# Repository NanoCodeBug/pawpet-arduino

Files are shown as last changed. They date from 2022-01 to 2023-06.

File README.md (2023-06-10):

# PawPet
Hi! This is the deprecated ardiuno-c++ based codebase, I've moved to a Rust codebase at https://github.com/NanoCodeBug/pawpet. 

# Build Instructions

Arduino SDK, pin layout of board is identical to a Adafruit Feather M0. 

## Linux Arduino SDK and Dependency Setup
tools/linux/sdk-setup.sh

tools/linux/build.sh

## Windows Arduino SDK and Dependency Setup
tools/win/sdk-setup.ps1

tools/win/build.ps1

## Mac Arduino SDK and Dependency Setup
tools/osx/sdk-setup.ps1

tools/osx/build.ps1

# Bootloader Instructions

1. flash adafruit bootloader https://github.com/adafruit/uf2-samdx1
2. set boot brotection fuses to 8kb (bootprot fuse value 0x2)
3. (optional) flash `pawos_setup.hex`
4. disable BOD33 fuse via `pawos_setup.hex` or preffered programmer device

# Flash Instructions

1. connect device via usb
2. double click reset button to enter bootloader
3. flash pawos via arduino-cli (`tools/<plat>/flash.sh`)

# Update Instructions
1. wake PawPet from sleep
2. connect via USB
3. flash pawos via arduino-cli (`tools/<plat>/flash.sh`)

TODO: update instructions that use UF2 instead, should be possible to use a script to put the device into bootloader mode, and then copy the file over via system file browser, or dynamically detect the device attach via usb id and drive name.

TODO: consider a self packaged C# exe or python script?

TODO: look into using openocd for flashing bootloader
TODO: fork adafruit bootloader to have low power operation enabled by default, bootloader blocks startup below 2.2v right now. in theory device can operate to 1.9v before display cuts out

---
# Simulator
A tool to simulate the pawpad on the computer.  
Currently only supports Windows.

## Requirements:

- [Visual Studio Community/MSVC](https://visualstudio.microsoft.com/vs/community/)
- [cmake](https://cmake.org/)
- [SDL2](https://github.com/libsdl-org/SDL/releases)
- [ninja](https://github.com/ninja-build/ninja/releases)
- [emsdk](https://emscripten.org/index.html) (Optional for webSimulator)

### Visual Studio Community
When setting up visual studio community, make sure to select these features:
"Desktop Development with C++"
as we require MSVC  
If you are using VSCode, see the following notes on launching VSCode from the Developer command prompt:  
(https://code.visualstudio.com/docs/cpp/config-msvc#_check-your-microsoft-visual-c-installation)

TODO: Could this possibly be switched to MinCG instead of using MSVC to remove the dependency of Visual Studio Community? [See here](https://code.visualstudio.com/docs/cpp/config-mingw)

### cmake
Install cmake to `C:\Program Files\CMake`

### SDL2
Download `SDL2-devel-[VERSION]-VC.zip` and place SDL2 in `.\simulator\SDL2`

### Ninja
Extract Ninja to `%userprofile%\dev\ninja.exe`

### emsdk
TODO

## Build the simulator
SDL2 and Webasm wrappers.

`tools/win/build.ps1 -simulator`

builds a SDL2 exe version of the pawpet, can be run from `.\build\win32\pawpet.exe`

`tools/win/build.ps1 -webSimulator`

builds a webasm version of the pawpet

## Controls
The Simulator uses the following controls:
```
 - Arrow Keys: dpad operation
 - Z - A Button: Open menu
 - X - B Button
 - C - C Button
 - V - P Button: Select
```

Additional Information in [simulator notes](simulator/notes.md)

---
# Licensing 

## Code
All code is licensed under the MIT license.

## Assets
Graphics, art, and models found in `sprites` and `paw-case` are licensed under the Creative Commons Attribution-NonCommercial 4.0 International Public License.

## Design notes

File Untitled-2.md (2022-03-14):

TODO:
validate clock toggle rate is 30hz and fix counters as needed 
need phillips screws for the back
need more heat set inserts
need more 470/480 ohm 805 resistors

https://forum.arduino.cc/t/samd21-power-consumption-too-high-in-active-mode/668966/2

Generic clock generator 0               8 division factor bits - DIV[7:0]
Generic clock generator 1               16 division factor bits - DIV[15:0]
Generic clock generators 2              5 division factor bits - DIV[4:0]
Generic clock generators 3 - 8          8 division factor bits - DIV[7:0]

rtc will be on anyways for time keeping

add BOD33 disable in bootloader flashing scripts?

condition where NVM RWS being 1 in bootloader will prevent startup below 2.1v
which is in theory near the end of useful battery life anyways

add ability for poweroff requiring push button reset?
from system menu and for when battery is low
- how to do this? disable all clocks?

display says it operates down 2.7v
- max frame frequency of 65hz?
- claims EXTCOMIN should be below framerate frequency, does not indicate why
- extcom freq of 54-65hz

3) A still image should be displayed less than two hours, if it is necessary to display still image longer than two 
hour, display image data must be refreshed in order to avoid sticking image on LCD panel

Memory LCDs do not generate this signal internally. It must be supplied using one of two methods: 
software, or external clock...
When the software clock is selected [EXTMODE = L], bit V of the command bit string sets the state of VCOM. 
See Figure 2. This bit must toggle (by writing to the panel) at least once per second. 

Power Scenario 1 
1hz write 1hz refresh
Here all of the pixels will be written to the panel once per second. For the 1.35-inch panel, the quiescent 
current for the panel is 2.1μA. Each write to the panel (assuming that the entire panel is written), takes 
360μA; and lasts for about 5.38ms (assuming a 2 MHz SPI clock speed). 
If averaged over a second, this amounts to an “average” currant draw of approximately 2μa. Therefore, the 
panel would have an average power draw of 20.5μW (5V operation). Note that a VCOM toggle can be done 
whenever the panel is written to, including a data write. 

Power Scenario 2 
30 sec write, 1hz refresh
Here, we write all the pixels to the panel only every 30 seconds. The current required to write to the panel 
“averaged” over that time is approximately 0.1μA. If VCOM is toggled once a second (using the Change 
VCOM command), the additional power draw for this action (assuming that it is done 29 times) is an average 
of 0.1μA. Therefore the average power draw over the 30-second period becomes 11.5μW. See Figure 10.
Applying these conditions to the 2.7-inch panel: writing all pixels to the whole panel once a second takes an 
average of 485μW. Writing all pixels once every 30 seconds (with a 1-second VCOM toggle) takes 135μW.

    uint32_t userWord0 = *((uint32_t *)NVMCTRL_USER);       // Read fuses for user word 0
    uint32_t userWord1 = *((uint32_t *)(NVMCTRL_USER + 4)); // Read fuses for user word 1
    NVMCTRL->CTRLB.bit.CACHEDIS = 1;                        // Disable the cache
    NVMCTRL->ADDR.reg = NVMCTRL_AUX0_ADDRESS / 2;           // Set the address
    NVMCTRL->CTRLA.reg = NVMCTRL_CTRLA_CMD_EAR |            // Erase the auxiliary user page row
                         NVMCTRL_CTRLA_CMDEX_KEY;
    while (!NVMCTRL->INTFLAG.bit.READY)             // Wait for the NVM command to complete
        NVMCTRL->STATUS.reg |= NVMCTRL_STATUS_MASK; // Clear the error flags
    NVMCTRL->ADDR.reg = NVMCTRL_AUX0_ADDRESS / 2;   // Set the address
    NVMCTRL->CTRLA.reg = NVMCTRL_CTRLA_CMD_PBC |    // Clear the page buffer
                         NVMCTRL_CTRLA_CMDEX_KEY;
    while (!NVMCTRL->INTFLAG.bit.READY)                            // Wait for the NVM command to complete
        NVMCTRL->STATUS.reg |= NVMCTRL_STATUS_MASK;                // Clear the error flags
    *((uint32_t *)NVMCTRL_USER) = userWord0 & ~FUSES_BOD33_EN_Msk; // Disable the BOD33 enable fuse in user word 0
    *((uint32_t *)(NVMCTRL_USER + 4)) = userWord1;                 // Copy back user word 1 unchanged
    NVMCTRL->CTRLA.reg = NVMCTRL_CTRLA_CMD_WAP |                   // Write to the user page
                         NVMCTRL_CTRLA_CMDEX_KEY;
    while (!NVMCTRL->INTFLAG.bit.READY)             // Wait for the NVM command to complete
        NVMCTRL->STATUS.reg |= NVMCTRL_STATUS_MASK; // Clear the error flags
    NVMCTRL->CTRLB.bit.CACHEDIS = 0;                // Enable the cache

pos 8, 5 bits
pos 15, 2 bits
pos 14, 1 bit

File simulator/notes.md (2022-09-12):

# TODO
- sleep support
- merge pawos.cpp and pawos.ino back together

## build
switch to pulling sdl2 from install path and not local?

# missing functions
- square/triangle audio generation in SDL with callback
- filesystem support
- better framerate syncing
- random supportvz

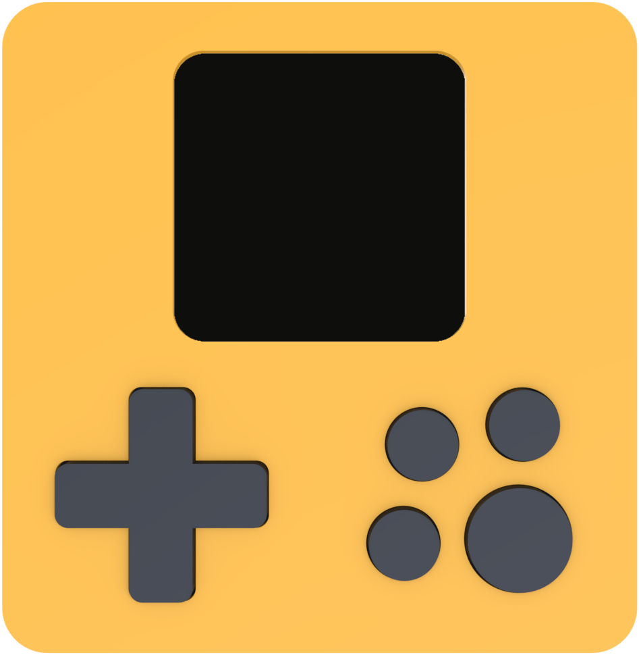
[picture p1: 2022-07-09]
simulator/case-front-graphic-none.png

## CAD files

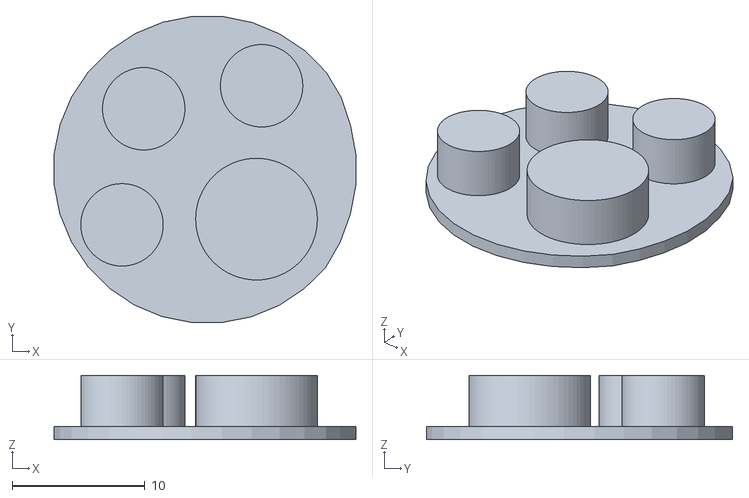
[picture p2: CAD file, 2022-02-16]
case/pawsome-v8-prod-r1-pawPad.stl
22.8 x 23.1 x 4.86

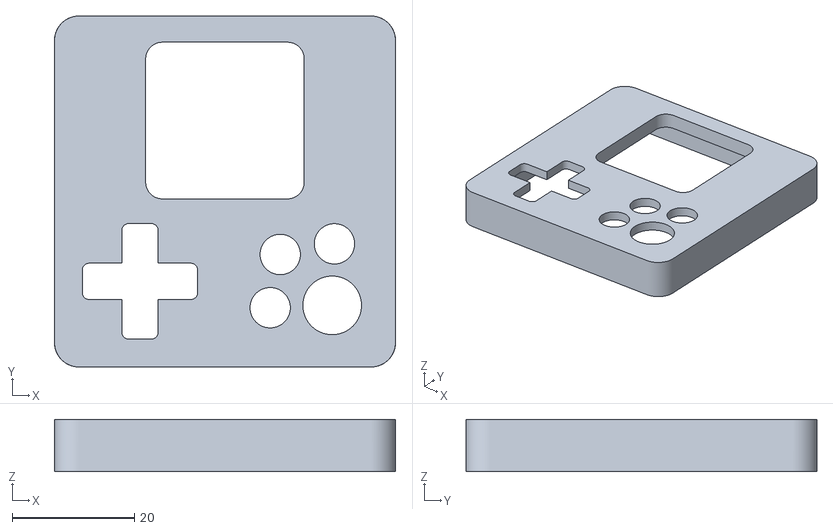
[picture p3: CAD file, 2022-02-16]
case/pawsome-v7-debug-r3-front.stl
55.9 x 57.5 x 8.56

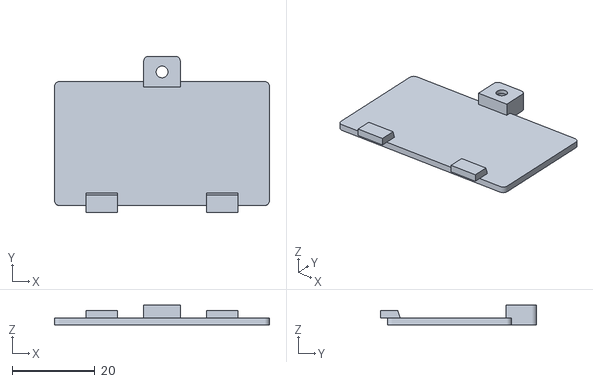
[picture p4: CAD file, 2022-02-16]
case/pawsome-v8-prod-r1-battery-door.stl
52.0 x 37.9 x 4.79

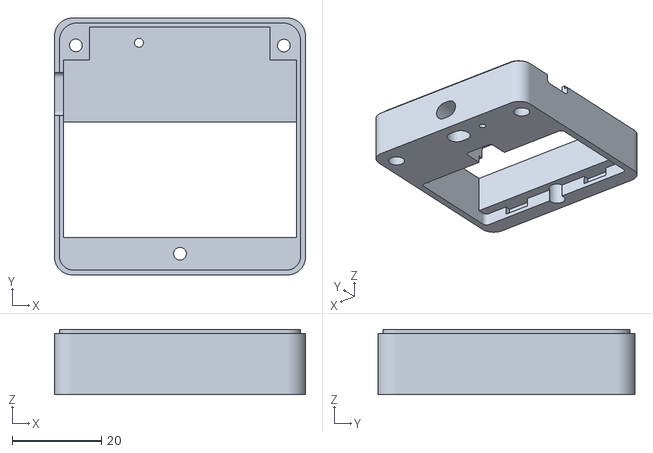
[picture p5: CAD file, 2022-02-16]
case/pawsome-v8-prod-r1-back.stl
56.2 x 57.5 x 14.7

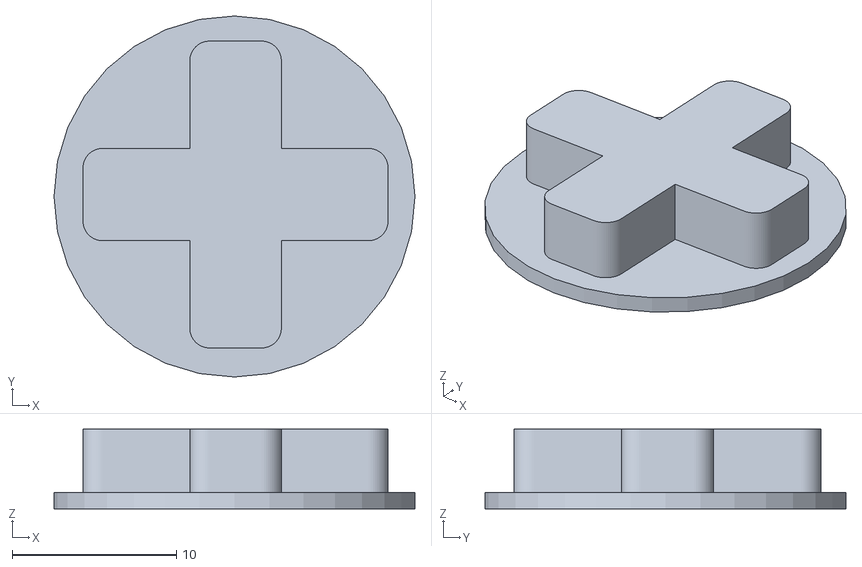
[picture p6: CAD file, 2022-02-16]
case/pawsome-v7-debug-r3-dPad.stl
22.0 x 22.0 x 4.87

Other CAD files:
case/pawsome-v7-debug-r3-pawPad.stl
case/pawsome-v7-debug-r3-back.stl
case/pawsome-v8-prod-r1-dPad.stl
case/pawsome-v8-prod-r1-front.stl
case/pawsome-v7-debug-r3-battery-door.stl

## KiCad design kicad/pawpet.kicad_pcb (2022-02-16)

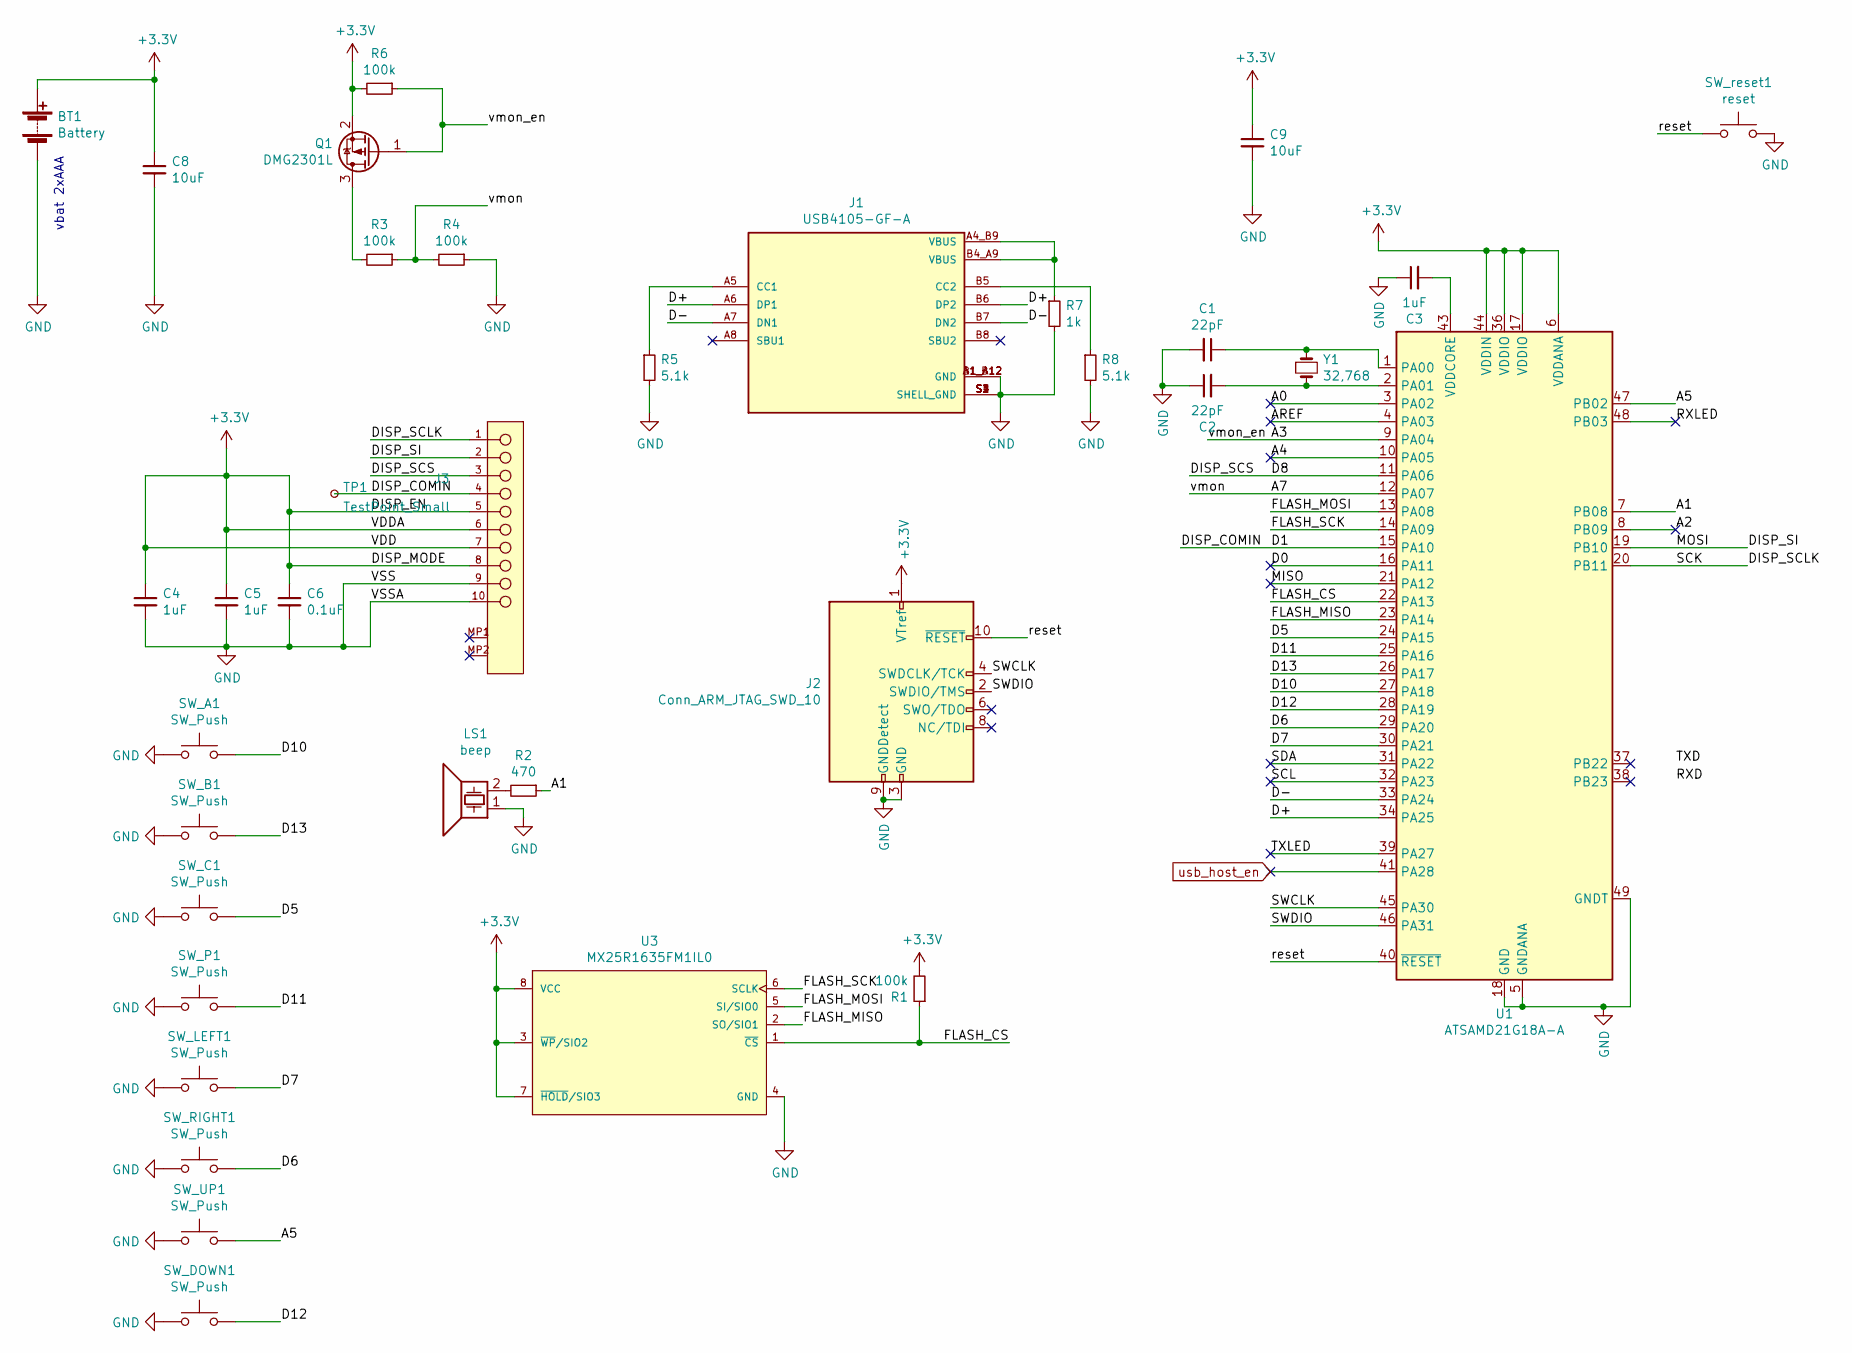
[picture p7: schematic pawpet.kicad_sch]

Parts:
BT1: Battery; BAT_BC2AAAPC
C1, C2: 22pF; C_0805_2012Metric
C3, C4, C5: 1uF; C_0805_2012Metric
C6: 0.1uF; C_0805_2012Metric
C8, C9: 10uF; C_0805_2012Metric
J1: USB4105-GF-A; GCT_USB4105-GF-A; PARTREV A3
J2: Conn_ARM_JTAG_SWD_10; Tag-Connect_TC2030-IDC-NL_2x03_P1.27mm_Vertical
J3: MOLEX; Molex-52892-1033-Manufacturer_Recommended
LS1: beep; Buzzer_Murata_PKMCS0909E4000-R1
Q1: DMG2301L; SOT-23
R1, R3, R4, R6: 100k; R_0805_2012Metric
R2: 470; R_0805_2012Metric
R5, R8: 5.1k; R_0805_2012Metric
R7: 1k; R_0805_2012Metric
SW_A1: SW_Push; SW_SPST_EVQQ2
SW_B1: SW_Push; SW_SPST_EVQQ2
SW_C1: SW_Push; SW_SPST_EVQQ2
SW_DOWN1: SW_Push; SW_SPST_EVQQ2
SW_LEFT1: SW_Push; SW_SPST_EVQQ2
SW_P1: SW_Push; SW_SPST_EVQQ2
SW_RIGHT1: SW_Push; SW_SPST_EVQQ2
SW_UP1: SW_Push; SW_SPST_EVQQ2
SW_reset1: reset; SW_SPST_PTS810_handsolder
TP1: TestPoint_Small; TestPoint_Pad_1.0x1.0mm
U1: ATSAMD21G18A-A; TQFP-48-1EP_7x7mm_P0.5mm_EP5x5mm
U3: MX25R1635FM1IL0; SOIC-8_5.23x5.23mm_P1.27mm
Y1: 32,768; Crystal_SMD_2012-2Pin_2.0x1.2mm

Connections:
+3V3: BT1.1 (+), C4.1, C5.1, C6.1, C8.1, C9.1, J2.1 (VTref), J3.5, J3.6, J3.7, J3.8, Q1.2 (S), R1.2, R6.2, U1.6 (VDDANA), U1.17 (VDDIO), U1.36 (VDDIO), U1.44 (VDDIN), U3.3 (~WP/SIO2), U3.7 (~HOLD/SIO3), U3.8 (VCC)
/A0: U1.3 (PA02)
/A1: R2.1, U1.7 (PB08)
/A2: U1.8 (PB09)
/A3: Q1.1 (G), R6.1, U1.9 (PA04)
/A4: U1.10 (PA05)
/A5: SW_UP1.2, U1.47 (PB02)
/A7: R3.1, R4.2, U1.12 (PA07)
/AREF: U1.4 (PA03)
/D0: U1.16 (PA11)
/D1: J3.4, TP1.1, U1.15 (PA10)
/D5: SW_C1.2, U1.24 (PA15)
/D6: SW_RIGHT1.2, U1.29 (PA20)
/D7: SW_LEFT1.2, U1.30 (PA21)
/D8: J3.3, U1.11 (PA06)
/D10: SW_A1.2, U1.27 (PA18)
/D11: SW_P1.2, U1.25 (PA16)
/D12: SW_DOWN1.2, U1.28 (PA19)
/D13: SW_B1.2, U1.26 (PA17)
/D+: J1.A6 (DP1), J1.B6 (DP2), U1.34 (PA25)
/D-: J1.A7 (DN1), J1.B7 (DN2), U1.33 (PA24)
/DISP_SCLK: J3.1, U1.20 (PB11)
/DISP_SI: J3.2, U1.19 (PB10)
/FLASH_CS: R1.1, U1.22 (PA13), U3.1 (~CS)
/FLASH_MISO: U1.23 (PA14), U3.2 (SO/SIO1)
/FLASH_MOSI: U1.13 (PA08), U3.5 (SI/SIO0)
/FLASH_SCK: U1.14 (PA09), U3.6 (SCLK)
/MISO: U1.21 (PA12)
/RXLED: U1.48 (PB03)
/SCL: U1.32 (PA23)
/SDA: U1.31 (PA22)
/SWCLK: J2.4 (SWDCLK/TCK), U1.45 (PA30)
/SWDIO: J2.2 (SWDIO/TMS), U1.46 (PA31)
/TXLED: U1.39 (PA27)
/reset: J2.10 (~RESET), SW_reset1.1, U1.40 (~RESET)
GND: BT1.2 (-), C1.2, C2.1, C3.1, C4.2, C5.2, C6.2, C8.2, C9.2, J1.A1_B12 (GND), J1.B1_A12 (GND), J1.S1 (SHELL_GND), J1.S2 (SHELL_GND), J1.S3 (SHELL_GND), J1.S4 (SHELL_GND), J2.3 (GND), J2.5 (GND), J2.9 (GNDDetect), J3.9, J3.10, LS1.1, R4.1, R5.2, R7.2, R8.2, SW_A1.1, SW_B1.1, SW_C1.1, SW_DOWN1.1, SW_LEFT1.1, SW_P1.1, SW_RIGHT1.1, SW_UP1.1, SW_reset1.2, U1.5 (GNDANA), U1.18 (GND), U1.35 (GND), U1.42 (GND), U1.49 (GNDT), U3.4 (GND)
unnamed: C1.1, U1.1 (PA00), Y1.1
unnamed: C2.2, U1.2 (PA01), Y1.2
unnamed: C3.2, U1.43 (VDDCORE)
unnamed: J1.A4_B9 (VBUS), J1.B4_A9 (VBUS), R7.1
unnamed: J1.A5 (CC1), R5.1
unnamed: J1.B5 (CC2), R8.1
unnamed: LS1.2, R2.2
unnamed: Q1.3 (D), R3.2
usb_host_en: U1.41 (PA28)

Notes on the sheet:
vbat 2xAAA

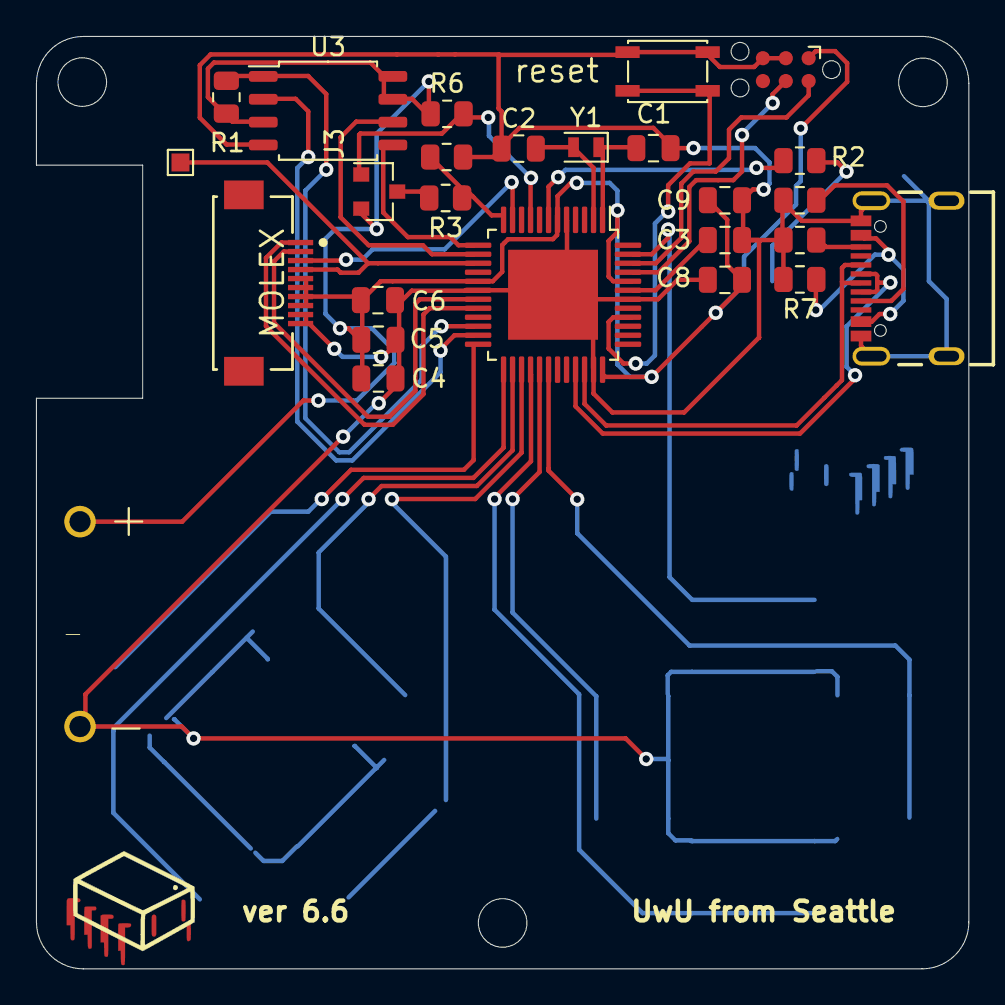
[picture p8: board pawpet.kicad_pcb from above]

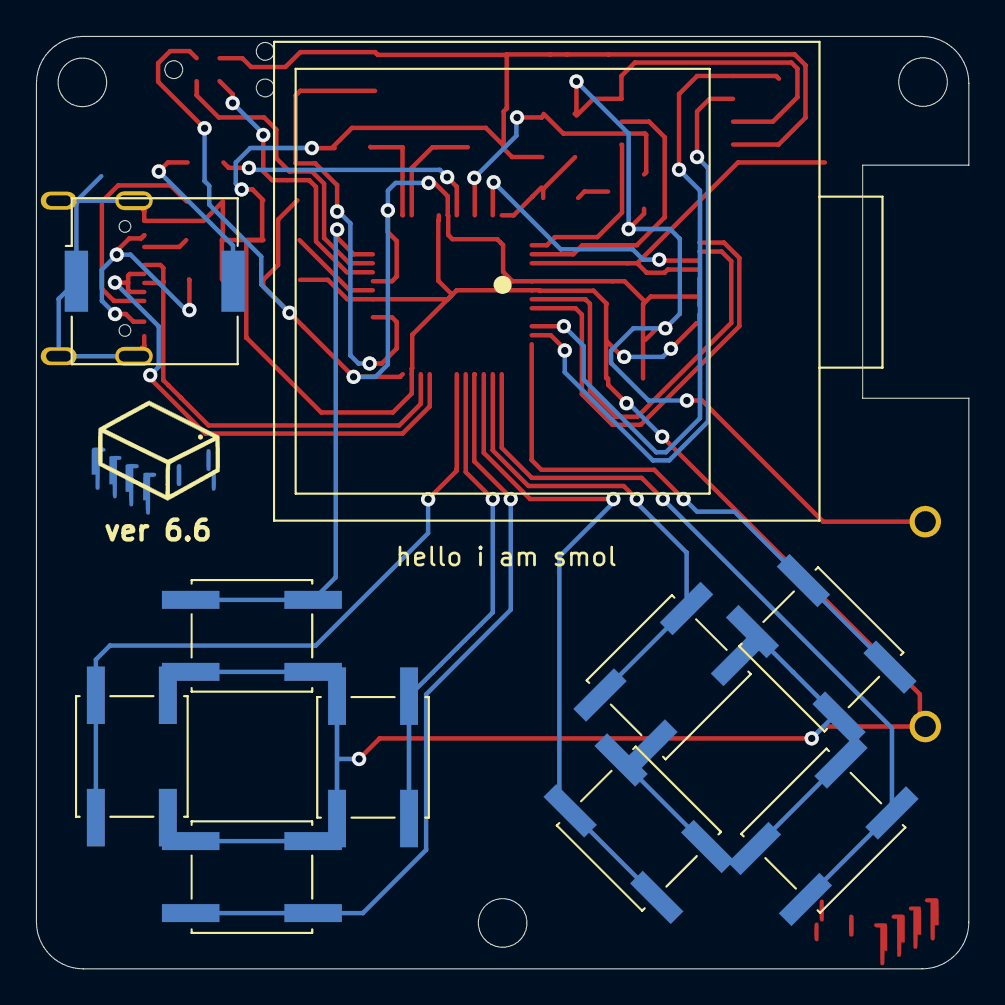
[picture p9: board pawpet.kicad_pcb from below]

Board: 2 copper layers, 51.8 x 51.8 mm, 38 parts (11 on the bottom side), 34 nets.

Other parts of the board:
Ref**: Val**; kicad-drawing
Ref**#2: Val**; kicad-drawing
hello i am smol: Sharp_128x128_LS013B7DH03

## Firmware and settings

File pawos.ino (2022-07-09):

#include <Adafruit_SPIFlash.h>
#include <Adafruit_TinyUSB.h>
#include <Arduino.h>
#include <FatLib/FatFileSystem.h>
#include <SPI.h>
#include <WInterrupts.h>
#include <wiring_private.h>

#include "src/lib/PawPet_InterruptHandler.h"
#include "src/lib/PawPet_FlashTransport.h"
#include "src/lib/RTCZero.h"

#include "src/common.h"
#include "src/config.h"
#include "src/global.h"
#include "src/lib/PawPet_SleepyDog.h"
#include "src/states/gamestate.h"

// #define DEBUG 1
// #define INSTALLER 1

#ifdef INSTALLER
#include "src/states/pawos_install.h"
#endif

#ifdef DEBUG
#include <ZeroRegs.h>
#endif

// TODO: Move setup of all devices elsewhere
// have the .ino to contain the core update loop only

static const SPIFlash_Device_t possible_devices[] = {MX25R1635F};
SPIClass flashSPI(&sercom2, FLASH_MISO, FLASH_SCK, FLASH_MOSI, SPI_PAD_0_SCK_1, SERCOM_RX_PAD_2);
PawPet_FlashTransport_SPI flashTransport(FLASH_CS, flashSPI);

SPIClass dispSPI(&sercom4, SHARP_MISO, SHARP_SCK, SHARP_MOSI, SPI_PAD_2_SCK_3, SERCOM_RX_PAD_0);
PetDisplay display(&dispSPI, SHARP_SS, DISP_WIDTH, DISP_HEIGHT);

// used by usb and button interrupts to keep the device awake when in use
volatile bool buttonWakeup;
volatile uint32_t nextSleepTime;

// button reading and interrupts
void buttonWakeupCallback();
uint8_t readButtons();

// gamestate and ui
bool drawTimeAndBattery();
GameState *currentState;

void disableUnusedClocks();

// USB Mass Storage object functions
Adafruit_USBD_MSC usb_msc;
int32_t msc_read_cb(uint32_t lba, void *buffer, uint32_t bufsize);
int32_t msc_write_cb(uint32_t lba, uint8_t *buffer, uint32_t bufsize, uint32_t tag);
void msc_flush_cb(void);
bool msc_ready_cb();
uint16_t intBat = 300;

File logFile;

void LogMsg(const char * msg)
{
    uint32_t uptime = (g::g_rtc.getEpoch() - g::g_stats.bootTime);
    uint32_t ontime = millis()/1000/60;
    uint16_t bat = Util::batteryLevel();

    // message, uptime, ontime, voltage, buttonWakeup
    logFile.printf("%s, %d, %d, %d, %d\n", msg, uptime, ontime, bat, buttonWakeup);
    logFile.sync();
}

void setup(void)
{
    g::g_flash = new Adafruit_SPIFlash(&flashTransport);
    Adafruit_SPIFlash& flash = *g::g_flash;

#ifdef DEBUG
    Serial.begin(9600);

    // wait for serial to attach
    while (!Serial) {}
#endif
    // power management
    disableUnusedClocks();

    // Watchdog._initialize_wdt();
    // WDT->CTRL.reg = 0; // Disable watchdog for config
    // while (WDT->STATUS.bit.SYNCBUSY) {};

    // set nvm wait states to 3, allowing for operation down to 1.6v
    // though display cuts out at 1.9v
    NVMCTRL->CTRLB.bit.RWS = 3;

    // setup pin mappings
    display.setRotation(DISP_ROTATION);
    display.begin();
    display.refresh();

    pinMode(PIN_BEEPER, OUTPUT);

    pinMode(PIN_BUTTON_A, INPUT_PULLUP);
    pinMode(PIN_BUTTON_B, INPUT_PULLUP);
    pinMode(PIN_BUTTON_C, INPUT_PULLUP);

    pinMode(PIN_BUTTON_P, INPUT_PULLUP);
    // InterruptHandler::attachInterruptWakeup(PIN_BUTTON_P, buttonWakeupCallback, FALLING);

    EExt_Interrupts in = g_APinDescription[PIN_BUTTON_P].ulExtInt;
    if (in == NOT_AN_INTERRUPT || in == EXTERNAL_INT_NMI)
        return;

    attachInterrupt(PIN_BUTTON_P, buttonWakeupCallback, FALLING);

    // enable EIC clock
    GCLK->CLKCTRL.bit.CLKEN = 0; // disable GCLK module
    while (GCLK->STATUS.bit.SYNCBUSY) {}

    GCLK->CLKCTRL.reg = (uint16_t)(GCLK_CLKCTRL_CLKEN | GCLK_CLKCTRL_GEN_GCLK3 |
                                   GCLK_CLKCTRL_ID(GCM_EIC)); // EIC clock switched on GCLK3
    while (GCLK->STATUS.bit.SYNCBUSY) {}

    // GCLK->GENCTRL.reg =
    //     (GCLK_GENCTRL_GENEN | GCLK_GENCTRL_SRC_OSCULP32K | GCLK_GENCTRL_ID(2) | GCLK_GENCTRL_RUNSTDBY); // source for
    //     GCLK2 is OSCULP32K
    // while (GCLK->STATUS.reg & GCLK_STATUS_SYNCBUSY) {}

    // GCLK->GENCTRL.bit.RUNSTDBY = 1; // GCLK2 run standby
    // while (GCLK->STATUS.reg & GCLK_STATUS_SYNCBUSY) {}

    // Enable wakeup capability on pin in case being used during sleep
    EIC->WAKEUP.reg |= (1 << in);

    /* Errata: Make sure that the Flash does not power all the way down
     * when in sleep mode. */

    NVMCTRL->CTRLB.bit.SLEEPPRM = NVMCTRL_CTRLB_SLEEPPRM_DISABLED_Val;

    pinMode(PIN_UP, INPUT_PULLUP);
    pinMode(PIN_LEFT, INPUT_PULLUP);
    pinMode(PIN_DOWN, INPUT_PULLUP);
    pinMode(PIN_RIGHT, INPUT_PULLUP);

    analogReadResolution(12);
    pinMode(PIN_VBAT, INPUT);
    pinPeripheral(PIN_VMON_EN, PIO_DIGITAL);
    pinMode(PIN_VMON_EN, OUTPUT);
    digitalWrite(PIN_VMON_EN, HIGH);

    flashSPI.begin();
    pinPeripheral(FLASH_MISO, PIO_SERCOM);
    pinPeripheral(FLASH_SCK, PIO_SERCOM_ALT);
    pinPeripheral(FLASH_MOSI, PIO_SERCOM_ALT);
    pinPeripheral(FLASH_CS, PIO_DIGITAL);

    flash.begin(possible_devices);

    // Init file system on the flash
    g::g_fatfs = new FatFileSystem();
    g::g_stats.filesysFound = g::g_fatfs->begin(&flash);
    g::g_stats.flashSize = flash.size();

    {
        // Set disk vendor id, product id and revision with string up to 8, 16, 4 characters respectively
        usb_msc.setID("Adafruit", "External Flash", "1.0");

        // Set callback
        usb_msc.setReadWriteCallback(msc_read_cb, msc_write_cb, msc_flush_cb);
        usb_msc.setReadyCallback(msc_ready_cb);

        // Set disk size, block size should be 512 regardless of spi flash page size
        usb_msc.setCapacity(flash.pageSize() * flash.numPages() / 512, 512);

        // MSC is ready for read/write
        usb_msc.setUnitReady(true);

        usb_msc.begin();
    }

    Watchdog.enable(WatchdogSAMD::WATCHDOG_TIMER_2_S);

    buttonWakeup = false;
    nextSleepTime = millis() + 40000;
#ifdef INSTALLER
    currentState = new InstallMenu();
#else
    currentState = new MenuState();
#endif

    g::g_rtc.begin();
    g::g_rtc.setHours(0);
    g::g_rtc.setMinutes(0);
    g::g_rtc.setSeconds(0);
    g::g_rtc.setDate(1, 1, (uint8_t)2022);
    g::g_stats.bootTime = g::g_rtc.getEpoch();

    intBat = Util::batteryLevel();

    logFile = g::g_fatfs->open("log.txt", FILE_WRITE);

    LogMsg("startup");

#ifdef DEBUG
    // dump registers for debugging power settings
    ZeroRegOptions opts = {Serial, false};
    printZeroRegs(opts);
#endif

#ifdef INSTALLER
    InstallUtils::SetFuses(false, 0x2);
    
    if(!g::g_stats.filesysFound)
    {
        InstallUtils::format();
    }
#endif

// disable and re-enable usb to get serial and usb msc at the same time
#ifndef DEBUG
    USBDevice.detach();
    delay(500);
    USBDevice.attach();
#endif
    if (!g::g_stats.filesysFound)
    {
        tone(PIN_BEEPER, NOTE_C4, 250);
    }
}

uint32_t sleepTicks = 0;
uint8_t keysState = 0;
uint8_t prevKeysState = 0;

uint32_t currentTimeMs = 0;
uint32_t frameTimeMs = 0;
uint32_t prevFrameMs = 0;

uint8_t droppedFrames = 0;
uint32_t peakUpdateTime = 0;
uint32_t peakDrawTime = 0;

uint16_t requestedFpsSleep = k_30_fpsSleepMs;

bool dirtyFrameBuffer = false;
void loop(void)
{
    Watchdog.fastReset();

    //// UPDATE ////
    keysState |= readButtons();

    currentTimeMs = millis();

    if (keysState)
    {
        nextSleepTime = currentTimeMs + 60000;
    }

    //// DRAW ////
    frameTimeMs = (currentTimeMs - prevFrameMs);
    if (frameTimeMs >= requestedFpsSleep)
    {
        prevFrameMs = currentTimeMs;
        // held is currenlty just previous update, a function of update loop speed
        // between 66 and 2000 ms
        g::g_keyPressed = ~(prevKeysState)&keysState;
        g::g_keyReleased = prevKeysState & ~(keysState);
        g::g_keyHeld = prevKeysState & keysState;

        uint32_t t1 = millis();
        GameState *nextState = currentState->update();
        uint32_t d1 = millis() - t1;
        peakUpdateTime = (d1 > peakUpdateTime) ? d1 : peakUpdateTime;

        if (nextState != currentState)
        {
            delete currentState;
            currentState = nextState;

            peakDrawTime = 0;
            peakUpdateTime = 0;

            switch (nextState->tick)
            {
            case k_tickTime30:
                requestedFpsSleep = k_30_fpsSleepMs;
                break;
            case k_tickTime15:
                requestedFpsSleep = k_15_fpsSleepMs;
                break;
            case k_tickTime5:
                requestedFpsSleep = k_5_fpsSleepMs;
                break;
            case k_tickTime1:
                requestedFpsSleep = k_1_fpsSleepMs;
                break;
            }

            intBat = Util::batteryLevel();
        }

        t1 = millis();
        if (currentState->redraw)
        {
            display.fillDisplayBuffer();
            display.setCursor(0, 8);
            display.setTextColor(PET_BLACK);
            currentState->draw(&display);

            // TODO, draw overlay should say if it needs an update
            dirtyFrameBuffer |= drawTimeAndBattery();

            dirtyFrameBuffer = true;
            currentState->redraw = false;
        }

        // display is done with dma transfer, approx 9ms
        if (!display.isFrameLocked())
        {
            if (dirtyFrameBuffer)
            {
                dirtyFrameBuffer = false;

                d1 = millis() - t1;
                peakDrawTime = (d1 > peakDrawTime) ? d1 : peakDrawTime;
                display.refresh();
            }
        }
        // display was still refreshing when next refresh was requested
        // somehow has hit a less than 10 ms draw time
        else if (currentState->redraw)
        {
            droppedFrames++;
        }

        prevKeysState = keysState;
        keysState = 0;
    }
    else
    {
        // skipped update + draw
        // sleep by amount remaining until next frame update?
        // would drop inputs though... sleep by some reasonable polling increment?
    }

    //// SLEEP ////
    if (currentTimeMs >= nextSleepTime)
    {
        intBat = Util::batteryLevel();

        if (intBat < 201)
        {
            // disable clocks and shutdown?
        }
        display.sync();

        buttonWakeup = false;
        // TODO: wakeup on flash chip not being triggered correctly
        // BUG: on reset after sleep flash doesn't show up until second reset
        // flashTransport.runCommand(0xB9); // deep sleep
        Watchdog.disable();
        LogMsg("s");

        // LowPower.deepSleep(k_sleepTimeMs);
        Watchdog.sleep(WatchdogSAMD::WATCHDOG_TIMER_64_S);
        LogMsg("w");

        Watchdog.enable(WatchdogSAMD::WATCHDOG_TIMER_2_S);

        // technically incriments on button wakeup as well, but this is fine
        sleepTicks++;

        //// SLEEP-BURN-IN-REFRESH ////
        // every 120 * k_sleepTimeMs refresh screen
        // display must be refreshed every 2 hours to avoid pixel burn-in
        if (sleepTicks >= 110)
        {
            sleepTicks = 0;
            display.fillDisplayBuffer();
            display.refresh();
            display.sync();

            // force redraw screen since it was cleared
            currentState->redraw = true;
        }

        //// SLEEP-UPDATE ////
        GameState *nextState = currentState->update();
        if (nextState != currentState)
        {
            delete currentState;
            currentState = nextState;
        }

        // TODO remove, being used to force overlay redraw in sleep mode
        // find better way to update every minute logic
        currentState->redraw = true;

        //// SLEEP-DRAW ////
        if (!display.isFrameLocked())
        {
            if (currentState->redraw)
            {
                display.fillDisplayBuffer();
                display.setCursor(0, 8);
                display.setTextColor(PET_BLACK);
                currentState->draw(&display);
                drawTimeAndBattery();
                dirtyFrameBuffer = true;
                currentState->redraw = false;
            }

            if (dirtyFrameBuffer)
            {
                dirtyFrameBuffer = false;
                display.refresh();
            }
        }
        display.sync();
    }
}

uint8_t readButtons()
{
    uint8_t inputState = 0;
    if (!digitalRead(PIN_BUTTON_A))
    {
        inputState |= BUTTON_A;
    }
    if (!digitalRead(PIN_BUTTON_B))
    {
        inputState |= BUTTON_B;
    }
    if (!digitalRead(PIN_BUTTON_P))
    {
        inputState |= BUTTON_P;
    }
    if (!digitalRead(PIN_BUTTON_C))
    {
        inputState |= BUTTON_C;
    }
    if (!digitalRead(PIN_UP))
    {
        inputState |= UP;
    }
    if (!digitalRead(PIN_LEFT))
    {
        inputState |= LEFT;
    }
    if (!digitalRead(PIN_DOWN))
    {
        inputState |= DOWN;
    }
    if (!digitalRead(PIN_RIGHT))
    {
        inputState |= RIGHT;
    }

    return inputState;
}

PetSprite _battery(battery);
bool drawTimeAndBattery()
{
    uint32_t elapsedTimeSeconds = currentTimeMs / 1000.0;
    // uint32_t hours = (elapsedTimeSeconds / 60 / 60);
    uint32_t minutes = (elapsedTimeSeconds / 60);
    uint32_t seconds = (elapsedTimeSeconds % 60);

    display.setCursor(0, 0);
    display.setTextColor(PET_WHITE, PET_BLACK); // inverted text
    display.fillRect(0, 0, 64, 8, PET_BLACK);

    // display.printf("%02u:%02u ", minutes, seconds);
    if (nextSleepTime > currentTimeMs)
    {
        display.printf("%02u %02u %02u", peakUpdateTime, peakDrawTime, droppedFrames % 100);
    }
    else
    {
        display.printf("Zz\n");
    }

    // 1.5*2 alk, 0.8v cutoff
    // 1.4*2 nimh? 1.0v cutoff
    //
    // discharge curves are non-linear, needs tunning
    // 2.6v >- full
    // 2.4v >- 3/4  - nimh spends most time here
    // 2.2v >- 2/4
    // 2.1v >- 1/4
    // 2.01v >- empty
    // 2.0v < shutdown, refuse to boot, below cutoff voltage
    // 1.9v - display will not turn on at this voltage
    // below 2v, display battery replace logo
    //
    // 2.7v - full
    // 2.6v - 3/4
    // 2.4v - 2/4SWS
    // 2.2v - 1/4
    // 2.0v - empty
    // 1.9v - display will not turn on
    // 1.6v cutoff, display will have already been inoperable

    uint8_t batFrame = 0;

    if (intBat > 260)
    {
        batFrame = 0;
    }
    else if (intBat > 240)
    {
        batFrame = 1;
    }
    else if (intBat > 220)
    {
        batFrame = 2;
    }
    else if (intBat > 210)
    {
        batFrame = 3;
    }
    else
    {
        batFrame = 4;
    }

    _battery.draw(&display, 48, 0, batFrame);
    // display.drawFrame("battery", 48, 0, batFrame);

    return true;
}

void buttonWakeupCallback()
{
    nextSleepTime = millis() + 60000;
    buttonWakeup = true;
    // {
    //     uint32_t t = (g::g_rtc.getEpoch() - g::g_stats.bootTime);

    //     logFile.printf("b: %d\n", t);
    //     logFile.sync();
    // }
}

// Callback invoked when received READ10 command.
// Copy disk's data to buffer (up to bufsize) and
// return number of copied bytes (must be multiple of block size)
int32_t msc_read_cb(uint32_t lba, void *buffer, uint32_t bufsize)
{
    // Note: SPIFLash Bock API: readBlocks/writeBlocks/syncBlocks
    // already include 4K sector caching internally. We don't need to cache it, yahhhh!!
    return g::g_flash->readBlocks(lba, (uint8_t *)buffer, bufsize / 512) ? bufsize : -1;
}

// Callback invoked when received WRITE10 command.
// Process data in buffer to disk's storage and
// return number of written bytes (must be multiple of block size)
int32_t msc_write_cb(uint32_t lba, uint8_t *buffer, uint32_t bufsize)
{
    // check_uf2_handover(buffer, bufsize, 4, 5, tag);
    // Note: SPIFLash Bock API: readBlocks/writeBlocks/syncBlocks
    // already include 4K sector caching internally. We don't need to cache it, yahhhh!!
    return g::g_flash->writeBlocks(lba, buffer, bufsize / 512) ? bufsize : -1;
}

// Callback invoked when WRITE10 command is completed (status received and accepted by host).
// used to flush any pending cache.
void msc_flush_cb(void)
{
    // sync with flash
    g::g_flash->syncBlocks();

    // clear file system's cache to force refresh
    g::g_fatfs->cacheClear();

    // changed = true;
}

bool msc_ready_cb(void)
{
    // usbConnectedTime = millis();
    nextSleepTime = millis() + 60000;
    return true;
}

void disableUnusedClocks()
{
    // disable standby usb
    USB->DEVICE.CTRLA.bit.RUNSTDBY = 0;

    // global clocks

    // Disable 8mhz GLCK 3 that bootloader has setup, unused?
    GCLK->CLKCTRL.reg = GCLK_CLKCTRL_GEN_GCLK3;
    while (GCLK->STATUS.bit.SYNCBUSY) {}

    GCLK->GENCTRL.reg = GCLK_GENCTRL_ID(3);
    while (GCLK->STATUS.bit.SYNCBUSY) {}

    // disable DAC clock
    GCLK->CLKCTRL.reg = GCLK_CLKCTRL_ID(GCM_DAC);
    while (GCLK->STATUS.bit.SYNCBUSY) {}

    // power manager
    // disable unused counters
    // TODO: find proper way of doing this
    uint32_t currSet = PM->APBCMASK.reg;

    currSet &= ~PM_APBCMASK_SERCOM0; // hardware serial
    currSet &= ~PM_APBCMASK_SERCOM1; // unused
    currSet &= ~PM_APBCMASK_SERCOM3; // i2c
    // why does GLCK_SERCOM4_CORE (flash) show up as set but not GLCK_SERCOM2_CORE (display)?
    // currSet &= ~PM_APBCMASK_SERCOM5; // debug port?

    // currSet &= ~PM_APBCMASK_TCC0; // unused... but bound to TCC0?
    // currSet &= ~PM_APBCMASK_TCC1; // vcom generator
    currSet &= ~PM_APBCMASK_TCC2;
    currSet &= ~PM_APBCMASK_TC3;
    currSet &= ~PM_APBCMASK_TC4;
    // currSet &= ~PM_APBCMASK_TC5; // tone generator
    currSet &= ~PM_APBCMASK_TC6;
    currSet &= ~PM_APBCMASK_TC7;
    currSet &= ~PM_APBCMASK_DAC;

    PM->APBCMASK.reg = currSet;
}

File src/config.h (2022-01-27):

#pragma once

/**
 * pin mappings and chip specific configurations
 * documents unused pins and changes to major board revisions
 */

#define M0_VER_5 1

const unsigned char BUILD_STRING[]{__TIME__[0], __TIME__[1], __TIME__[3], __TIME__[4], __DATE__[0],
                                   __DATE__[1], __DATE__[2], __DATE__[4], __DATE__[5], '\0'};

#define DISP_WIDTH 128
#define DISP_HEIGHT 128

#if defined(M0_VER_5) || defined(M0_VER_6)
// 0 RX
#define DISP_COMIN 1 // PORTA, 10
#define FLASH_MISO 2 // PORTA, 14
#define FLASH_SCK 3  // PORTA, 9
#define FLASH_MOSI 4 // PORTA, 8
#define PIN_BUTTON_C 5
#define PIN_RIGHT 6
#define PIN_LEFT 7
#define SHARP_SS 8
#define PIN_VBAT 9 // A7
#define PIN_BUTTON_A 10
#define PIN_BUTTON_P 11
#define PIN_DOWN 12
#define PIN_BUTTON_B 13
// 14 A0
#define PIN_BEEPER 15 // A1
// 16 A2
#define PIN_VMON_EN 17 // A3
// 18 A4
#define PIN_UP 19     // A5
                      // SDA 20 no pullup?
                      // SCL 21 no pullup?
#define SHARP_MISO 22 // MISO
#define SHARP_MOSI 23 // MOSI
#define SHARP_SCK 24  // SCK
#define FLASH_CS 38   // PORTA, 13

#define RAM_SIZE 32000

#define DISP_ROTATION 1
#endif

// #define MX25R1635F                                                                                                     \
//     {                                                                                                                  \
//         .total_size = (1 << 21), /* 2 MB / 16 Mb */                                                                    \
//             .start_up_time_us = 800, .manufacturer_id = 0xc2, .memory_type = 0x28, .capacity = 0x15,                   \
//         .max_clock_speed_mhz = 33 /*8*/, .quad_enable_bit_mask = 0x40, .has_sector_protection = false,                 \
//         .supports_fast_read = true, .supports_qspi = true, .supports_qspi_writes = true,                               \
//         .write_status_register_split = false, .single_status_byte = true,                                              \
//     }

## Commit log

2021-12-18 power opt tests
    [pawpet-v6.kicad_pcb]
2021-12-30 low power tests
2022-01-25 forked sleepydog to modify clock divisor for longer watchdog timers
2022-01-25 update schematic and stls
    [pawpet-v6.kicad_pcb, pawpet.kicad_pcb, pawpet.kicad_sch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]
2022-01-27 updated to use latest adafruit samd base and gclk output to display vcom
    [pawpet.kicad_pcb, pawpet.kicad_sch, pawsome-v6-debug-r2-dPad.stl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]
2022-01-27 updated case and flash script
    [pawsome-v7-debug-r3-back.stl, pawsome-v7-debug-r3-battery-door.stl, pawsome-v7-debug-r3-dPad.stl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]
2022-02-04 fixed bug in watchdog clock not being mapped, fix broke usb due to cost of doing reset delay
    [display.cpp, pawos.ino]
2022-02-16 update to latest schematic, pcb, and stl files
    [pawpet.kicad_pcb, pawpet.kicad_sch, pawsome-v7-debug-r3-back.stl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]
2022-03-13 setup env for testing and setting fuses
2022-03-14 package test
    [pawpet_m0.cfg, pawsome-v7-debug-r3-back.stl, pawsome-v7-debug-r3-battery-door.stl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]
2022-03-14 remake package
    [pawpet_m0.cfg]
2022-03-14 rev package
    [pawpet_m0.cfg]
2022-03-15 fix package dependencies, add jlink support
    [pawos.ino]
2022-03-19 move files around
    [pawpet_m0.cfg]
2022-09-12 build and simulator fixes
    [main.cpp]
2022-09-12 updating to fix linux build compat
    [main.cpp]
